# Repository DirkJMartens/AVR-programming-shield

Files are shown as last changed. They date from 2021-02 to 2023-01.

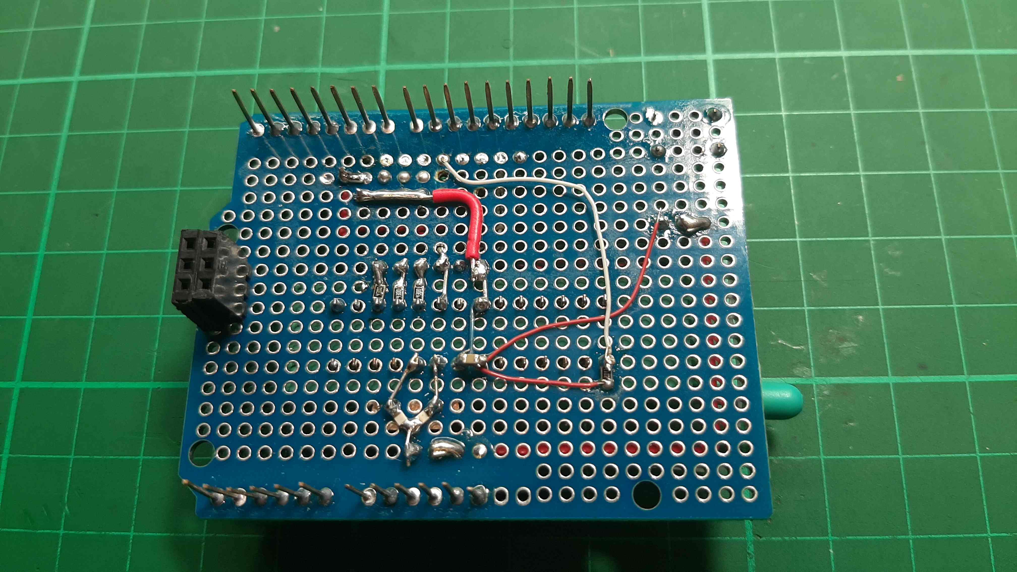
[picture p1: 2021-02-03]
AVR_ISP_programmer_bottom.jpg

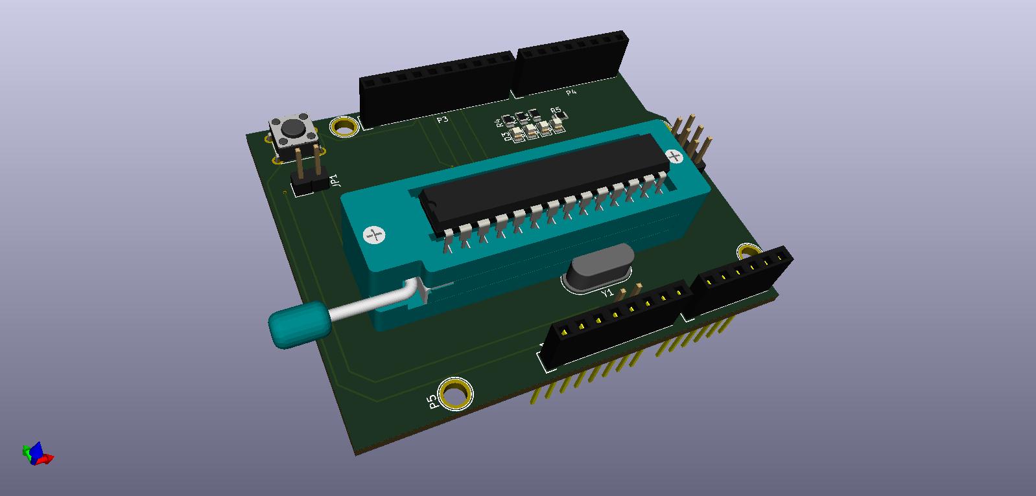
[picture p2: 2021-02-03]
AVR-ISP-programmer_top.jpg

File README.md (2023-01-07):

# AVR-programming-shield
Arduino shield with ZIF socket to program sketches or bootloaders into 28-pin ATMega microcontrollers. 

Usage for sketches: 
===================
1. Install shield onto an Arduino Uno. 
2. Install the target AVR chip into the ZIF socket on the shield. 
3. Connect USB cable between your computer and Arduino Uno. 
4. The (blue) "Power" led should light up on the shield. 
5. Launch the Arduino IDE and load the "ArduinoISP" sketch from the "File - Examples" menu. 
6. Select "Tools - Board" to "Arduino Uno" and "Tools - Port" to the appropriate COM port 
7. Select "Sketch - Upload" to compile and upload the ArduinoISP sketch into your Uno. 
8. The (green) "Heartbeat" led should now fade in and out. 
9. Open the sketch you want to upload into the target AVR chip. 
10. Change the "Tools - Board" to e.g. "Arduino on a breadboard (8 MHz internal clock)". 
11. Change the "Tools - Programmer" to "Arduino as ISP" 
12. Select "Tools - Upload using Programmer" (not Upload). 
13. The sketch will be compiled and uploaded. 
14. During upload, the (amber) "Programming" led should light up. 
15. If the upload was successsful, the (green) "Heartbeat" light should fade in and out again. 
16. If the upload was unsuccesful, the (red) "Error" light should light up. 

Usage for bootloader uploading: 
===============================
1. Repeat steps 1 through 8 above. 
2. Change "Tools - Board" to e.g. "Arduino on a breadboard (8 MHz internal clock)". 
3. Change "Tools - Programmer" to "Arduino as ISP". 
4. Change "Port" to the appropriate port. 
5. Select "Tools - Burn bootloader". 
6. Similar to above, the (amber) "Programming" led should light up during programming. 
7. Upon completion, the (green) "Heartbeat" led should fade or in case of a problem, the (red) "Error" light will light up.

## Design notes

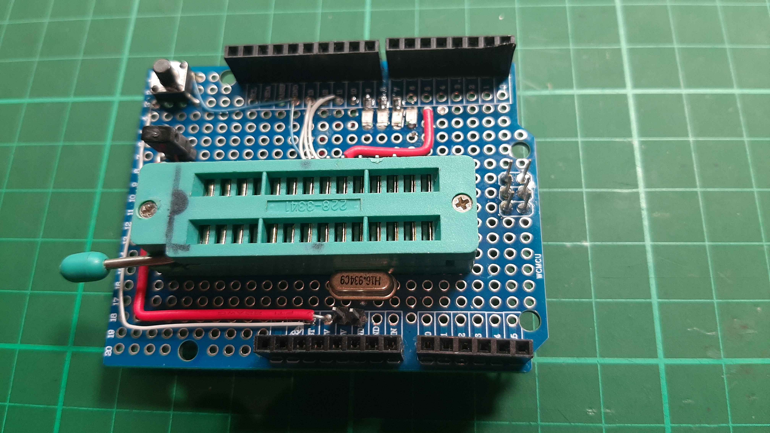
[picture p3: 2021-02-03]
AVR_ISP_programmer_top.jpg

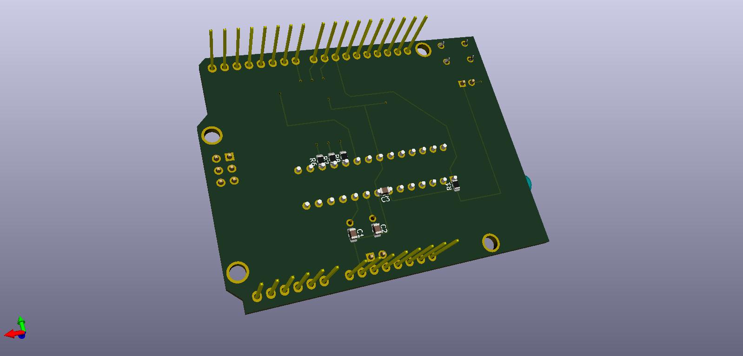
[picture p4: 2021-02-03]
AVR-ISP-programmer_bottom.jpg

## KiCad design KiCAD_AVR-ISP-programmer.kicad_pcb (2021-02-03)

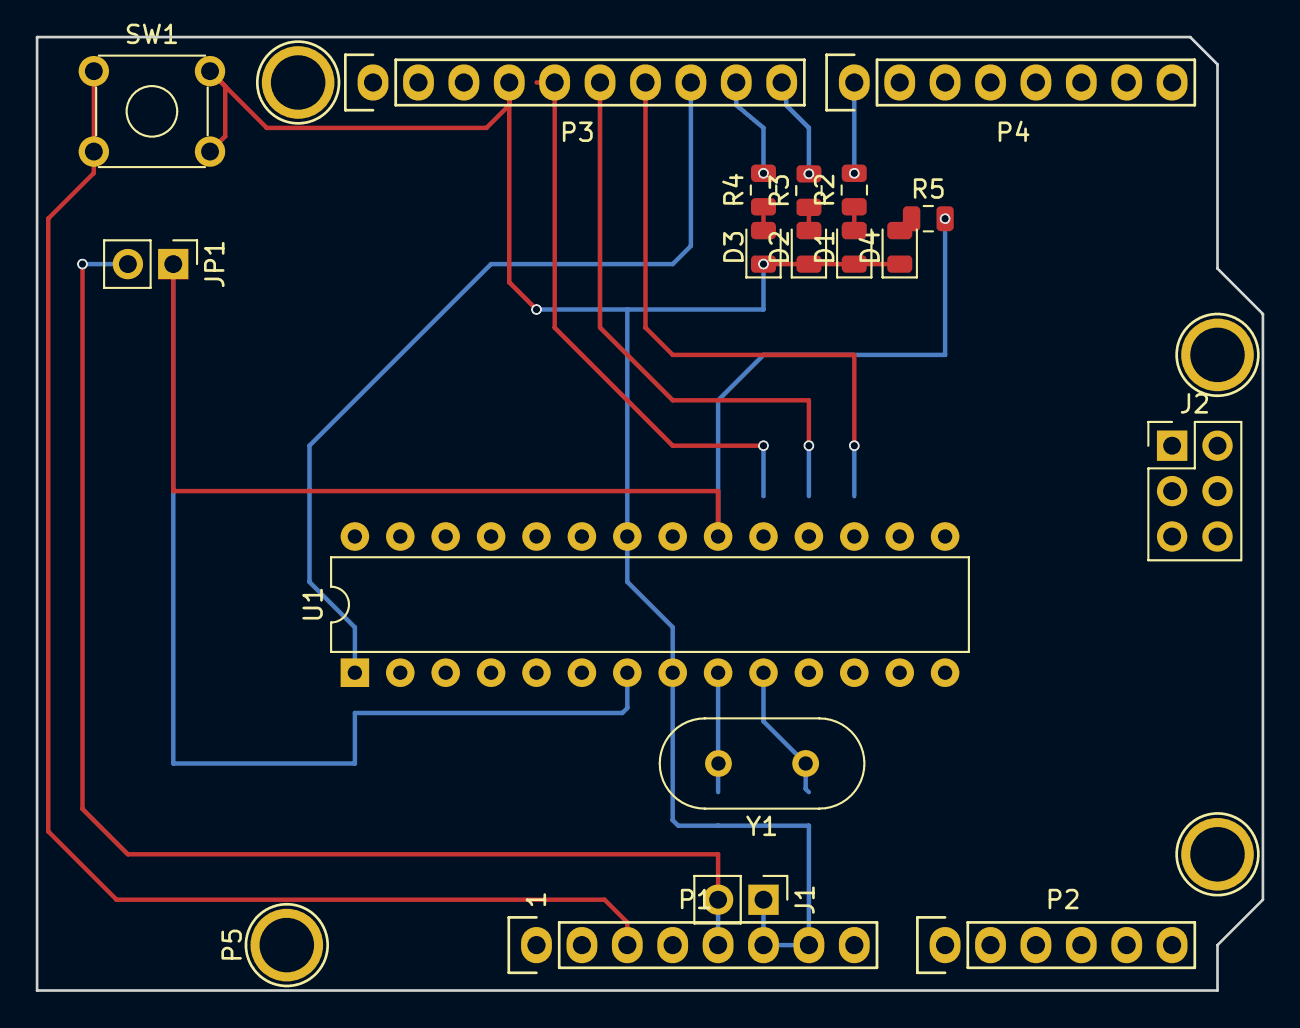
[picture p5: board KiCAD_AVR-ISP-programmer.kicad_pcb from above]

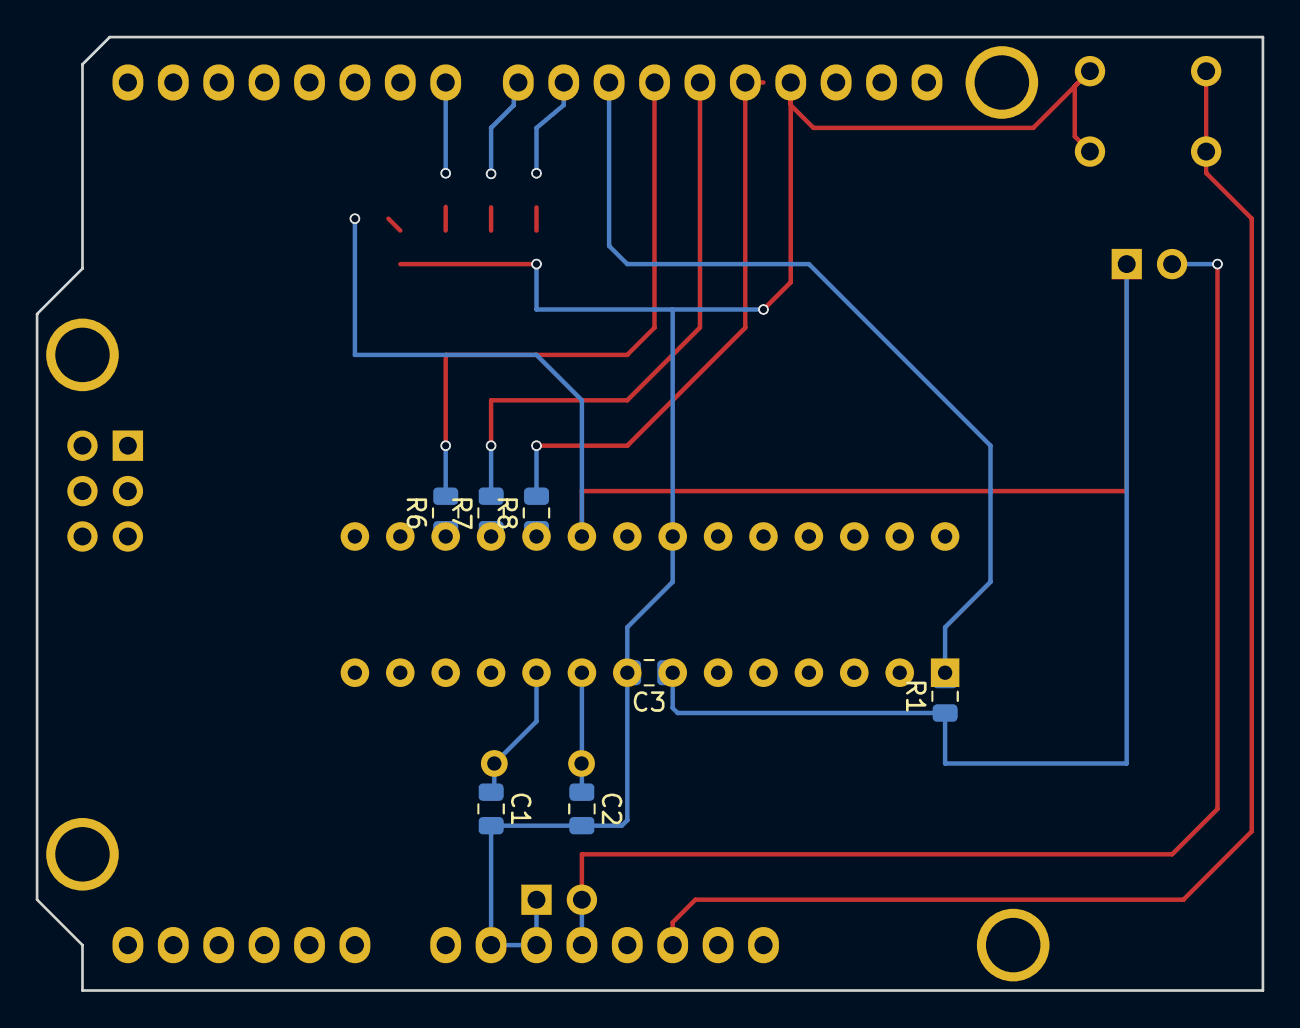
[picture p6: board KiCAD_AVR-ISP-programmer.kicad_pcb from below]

Board: 2 copper layers, 68.6 x 53.3 mm, 29 parts (7 on the bottom side), 20 nets.

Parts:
C1, C2: 22p; C_0805_2012Metric
C3: 100n; C_0805_2012Metric
D1: OK (Amber); LED_0805_2012Metric
D2: ERROR (Red); LED_0805_2012Metric
D3: PROGRAM (Green); LED_0805_2012Metric
D4: POWER (Blue); LED_0805_2012Metric
J1: 5V-GND; PinHeader_1x02_P2.54mm_Vertical
J2: ICSP6; PinHeader_2x03_P2.54mm_Vertical
JP1: PWR; PinHeader_1x02_P2.54mm_Vertical
P1: Power; Socket_Strip_Arduino_1x08
P2: Analog; Socket_Strip_Arduino_1x06
P3: Digital; Socket_Strip_Arduino_1x10
P4: Digital; Socket_Strip_Arduino_1x08
P5, P6, P7, P8: CONN_01X01; Arduino_1pin
R1: 10k; R_0805_2012Metric
R2, R3, R4, R5: 2k4; R_0805_2012Metric
R6, R7, R8: 470; R_0805_2012Metric
SW1: RESET; SW_TH_Tactile_Omron_B3F-10xx
U1: ATmega328P-PU; DIP-28_W7.62mm
Y1: 16.934MHz; Crystal_HC49-4H_Vertical

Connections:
+5V: J1.2, JP1.2, P1.5
/7: P4.1, R2.2
/8: P3.10, R3.2
/9(**): P3.9, R4.2
/10(~SS): P3.8, R1.2, U1.1
/11(~MOSI): P3.7, R6.2
/12(MISO): P3.6, R7.2
/13(SCK): P3.5, R8.2
/Reset: P1.3, SW1.1, SW1.3
GND: C1.2, C2.2, C3.2, D1.1, D2.1, D3.1, D4.1, J1.1, P1.6, P1.7, P3.4, SW1.2, SW1.4, U1.8, U1.22
unnamed: C1.1, U1.10, Y1.1
unnamed: C2.1, U1.9, Y1.2
unnamed: C3.1, JP1.1, R1.1, R5.2, U1.7, U1.20
unnamed: D1.2, R2.1
unnamed: D2.2, R3.1
unnamed: D3.2, R4.1
unnamed: D4.2, R5.1
unnamed: R6.1, U1.17
unnamed: R7.1, U1.18
unnamed: R8.1, U1.19

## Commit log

2023-09-18 Update and rename AVR-ISP-programmer.kicad_pcb to KiCAD_AVR-ISP-programmer.kicad_pcb
    [KiCAD_AVR-ISP-programmer.kicad_pcb]
2023-09-18 Update and rename AVR-ISP-programmer.sch to KiCAD_AVR-ISP-programmer.sch
    [KiCAD_AVR-ISP-programmer.sch]
